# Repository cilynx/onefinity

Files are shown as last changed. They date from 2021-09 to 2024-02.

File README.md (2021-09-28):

# Onefinity
Customizations and Extensions for Onefinity CNC Machines

## Calibration

Easy to work with objects of known dimensions for validating everything is dialed in correctly.

## Pen Plotter

Plot with multiple pens and automatic color changes.

Onefinity CNC: Pen Plotter Multi-Row Magazine (https://youtu.be/0U2Qaqqsit8)

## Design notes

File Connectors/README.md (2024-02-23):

# Stock Onefinity Connectors

| Manufacturer | Amazon | Digikey | Mouser | Description | Use |
| - | - | - | - | - | - |
| [Molex 39-01-3046](https://www.molex.com/pdm_docs/sd/039013046_sd.pdf) | [B07DLLN2VL](https://amzn.to/46uqZdA) (5-circuit set of pins and housings) | [WM17195-ND](https://www.digikey.com/en/products/detail/molex/0039013046/7062835) | [538-39-01-3046](https://www.mouser.com/ProductDetail/Molex/39-01-3046?qs=1XlfjIQj4rzRlofcDRhtUQ%3D%3D) | Mini-Fit Jr. 4 Pin Female Inline Housing (4.20mm pitch). Use with 39-00-0041 Pins. | M0-M3 connection blocks built into the rails. |
| [Molex 39-00-0041](https://www.molex.com/pdm_docs/sd/039000041_sd.pdf) | [B07DLLN2VL](https://amzn.to/46uqZdA) (5-circuit set of pins and housings) | [WM2500-ND](https://www.digikey.com/en/products/detail/molex/0039000041/61445) | [538-39-00-0041](https://www.mouser.com/ProductDetail/Molex/39-00-0041/?qs=jsoPY5EnoNugPq%2FRPe5I8w%3D%3D) | Mini-Fit Jr. Male Crimp Pin. Use with 39-01-3046 Housings. | Pins for the above housing. |
| [Molex 39-01-3045](https://tools.molex.com/pdm_docs/sd/039013045_sd.pdf) | [B07DLLN2VL](https://amzn.to/46uqZdA) (5-circuit set of pins and housings) | [WM13487-ND](https://www.digikey.com/en/products/detail/molex/0039013045/3160117) | [538-39-01-3045](https://www.mouser.com/ProductDetail/Molex/39-01-3045/?qs=1XlfjIQj4rw5awNar2tWGQ%3D%3D) | Mini-fit Jr 4 Pin Male Inline Housing (4.20mm pitch). Use with 39-00-0039 Female Pins | M0-M3 cable ends that plug into the blocks on the rails. |
| [Molex 39-00-0039](https://www.molex.com/pdm_docs/sd/039000039_sd.pdf) | [B07DLLN2VL](https://amzn.to/46uqZdA) (5-circuit set of pins and housings) | [WM2501-ND](https://www.digikey.com/en/products/detail/molex/0039000039/61448) | [538-39-00-0039](https://www.mouser.com/ProductDetail/Molex/39-00-0039/?qs=jsoPY5EnoNukaZLXtX9KoA%3D%3D) | Mini-Fit Jr. Female Crimp Pin. Use with 39-01-3045 Housings | Pins for the above housing. |
| [Molex 11-03-0044](https://tools.molex.com/pdm_docs/ats/ATS-011030044.pdf) | [B08LHDH9KN](https://amzn.to/44uFX1e) | [WM9918-ND](https://www.digikey.com/en/products/detail/molex/0011030044/210947) | [538-11-03-0044](https://www.mouser.com/ProductDetail/Molex/11-03-0044?qs=zb2cXSD1GSER3iz39m7%252B5g%3D%3D) | Extraction Tool for Mini-Fit Jr. Crimp Pins |
| [Amphenol 10127716-04LF](https://www.amphenol-cs.com/minitek-pwr-3-0-1012771604lf.html) | [B078Q798L9](https://amzn.to/3PH550O) (5-circuit set of pins and housings) | [609-4816-ND](https://www.digikey.com/en/products/detail/amphenol-cs-fci/10127716-04LF/4996158) | [649-10127716-04LF](https://www.mouser.com/ProductDetail/Amphenol-FCI/10127716-04LF?qs=Bf%2FVgRlSfyE9WovoNUAZ0w%3D%3D) | Minitek Pwr 3.0 Male Inline Housing (3mm pitch). Use with 10127718-001LF Female Pins. | M0-M3 cable ends that plug into the blocks on the Buildbotics controller. |
| [Amphenol 10127718-001LF](https://www.amphenol-cs.com/minitek-pwr-3-0-10127718001lf.html) | [B078Q798L9](https://amzn.to/3PH550O) (5-circuit set of pins and housings) | [609-4845-1-ND](https://www.digikey.com/en/products/detail/amphenol-cs-fci/10127718-001LF/4996181) | [649-10127718-001LF](https://www.mouser.com/ProductDetail/Amphenol-FCI/10127718-001LF?qs=Bf%2FVgRlSfyE%2FaXnoRiR86A%3D%3D) | Minitek Pwr 3.0 Female Crimp Pin. Use with 10127716-04LF housings. | Pins for the above housing. |
| [Amphenol 10127717-04LF](https://www.amphenol-cs.com/minitek-pwr-3-0-1012771704lf.html) | [B078Q798L9](https://amzn.to/3PH550O) (5-circuit set of pins and housings) | [609-4824-ND](https://www.digikey.com/en/products/detail/amphenol-cs-fci/10127717-04LF/4996170) | [649-10127717-04LF](https://www.mouser.com/ProductDetail/Amphenol-FCI/10127717-04LF?qs=Bf%2FVgRlSfyENFCymmLKBBg%3D%3D) | Minitek Pwr 3.0 Female Inline Housing (3mm pitch). Use with 10127719-001LF Male Pins. | M0-M3 connection blocks built into the Buildbotics controller. |
| [Amphenol 10127719-001LF](https://www.amphenol-cs.com/minitek-pwr-3-0-10127719001lf.html) | [B078Q798L9](https://amzn.to/3PH550O) (5-circuit set of pins and housings) | [609-4846-1-ND](https://www.digikey.com/en/products/detail/amphenol-cs-fci/10127719-001LF/4996185) | [649-10127719-001LF](https://www.mouser.com/ProductDetail/Amphenol-FCI/10127719-001LF?qs=Bf%2FVgRlSfyFCUst32mYSEg%3D%3D) | Minitek Pwr 3.0 Male Crimp Pin. Use with 10127717-04LF housings. | Pins for the above housing. |
| [Amphenol 10129274-030LF](https://www.amphenol-cs.com/minitek-pwr-3-0-cable-assembly-10129274030lf.html) | [B0195V4OVA](https://amzn.to/433VgwZ) | [609-5574-ND](https://www.digikey.com/en/products/detail/amphenol-cs-fci/10129274-030LF/5185630) | [649-10129274-030LF](https://www.mouser.com/ProductDetail/Amphenol-FCI/10129274-030LF?qs=cgQJD%2FpJz0xA4ycwVwK8Zw%3D%3D) | Extraction Tool for Minitek Pwr 3.0 Crimp Pins |

Inspired by [this thread](https://forum.onefinitycnc.com/t/wire-connections/1880) on the Onefinity Forum.  

It's worth noting that Minitek Pwr 3.0 and 4.2 are [interchangeable and inter-pluggable](https://www.automation.com/en-us/products/product08/fci-announces-minitek-pwr-30-42-connectors) with Molex Micro-Fit and Mini-Fit Jr. respectively.  

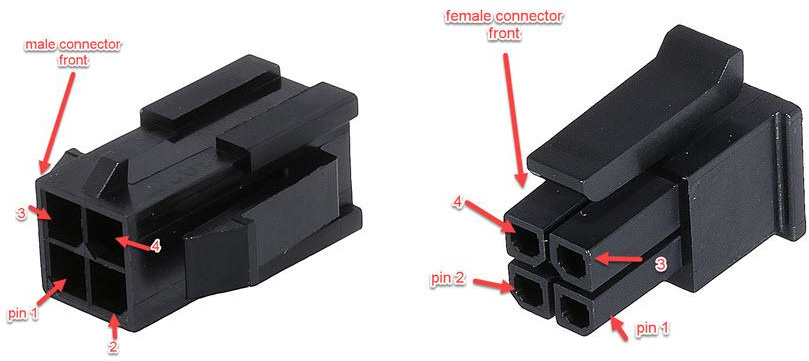
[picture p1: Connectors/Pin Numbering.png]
pins


# BTT Octopus v1.1

| Header | Code | Pins | Default Function | Octofinity Function | Connector | Issues |
| - | - | - | - | - | - | - |
| J3 | MOTOR0 || X-Axis | M0 (X-Axis) | 4-pin JST XH | https://github.com/cilynx/onefinity/issues/3 |
| J4 | MOTOR1 || Y-Axis || 4-pin JST XH |
| J7 | MOTOR2_1 || Z-Axis | M3 (Z-Axis) | 4-pin JST XH | https://github.com/cilynx/onefinity/issues/3 |
| J5 | MOTOR2_2 || Z-Axis 2 (for dual-Z) | | 4-pin JST XH |
| J6 | MOTOR3 || Accessory || 4-pin JST XH |
| J10 | MOTOR4 || Extruder 0 | M4 (Extruder) | 4-pin JST XH | https://github.com/cilynx/onefinity/issues/2, https://github.com/cilynx/onefinity/issues/3 |
| J11 | MOTOR5 || Extruder 1 | M1 (Y-Axis 0) | 4-pin JST XH | https://github.com/cilynx/onefinity/issues/3 |
| J13 | MOTOR6 || Extruder 2 | M2 (Y-Axis 1) | 4-pin JST XH | https://github.com/cilynx/onefinity/issues/3 |
| J12 | MOTOR7 || Extruder 3 || 4-pin JST XH |
| J26 | Raspberry Pi | PD5 (TX2), PD6 (RX2) | Raspberry Pi || 2x5 Dupont |
| J40 | SENSOR | PB7 | Touch Probe | Touch Probe | 3-pin JST XH |
| J43 | BL_TOUCH | PB6, PB7 | [BLTouch Probe](https://amzn.to/44pBa0Y) || 1x5 Dupont |
| J44 | TB | PF3 | Bed Temperature || 2-pin JST XH |
| J45 | T0 | PF4 | Extruder 0 Temperature | Extruder Temperature | 2-pin JST XH | https://github.com/cilynx/onefinity/issues/1 |
| J46 | T1 | PF5 | Extruder 1 Temperature || 2-pin JST XH |
| J48 | T2 | PF6 | Extruder 2 Temperature || 2-pin JST XH |
| J49 | T3 | PF7| Extruder 3 Temperature || 2-pin JST XH |
| J50 | FAN0 | PA8 | Print cooling fan || 2-pin JST XH |
| J51 | FAN1 | PE5 | Heater fan 1 | Extruder Fan | 2-pin JST XH | https://github.com/cilynx/onefinity/issues/1 |
| J52 | FAN2 | PD12 | Heater fan 2 || 2-pin JST XH |
| J53 | FAN3 | PD13 | Heater fan 3 || 2-pin JST XH |
| J54 | FAN4 | PD14 | Heater fan 4 || 2-pin JST XH |
| J55 | FAN5 | PD15 | Heater fan 5 || 2-pin JST XH |
| J57 | FAN6 || Always-on fan 0 || 2-pin JST XH | https://github.com/cilynx/onefinity/issues/4 |
| J56 | FAN7 || Always-on fan 1 || 2-pin JST XH |
| J70 | TFT | PA9 (TX1), PA10 (RX1) | TFT Display || 5-pin JST XH |
| J73 | I2C & EEPROM | PB8 (SCL), PB9 (SDA) | I2C & EEPROM || 2x4 Dupont |

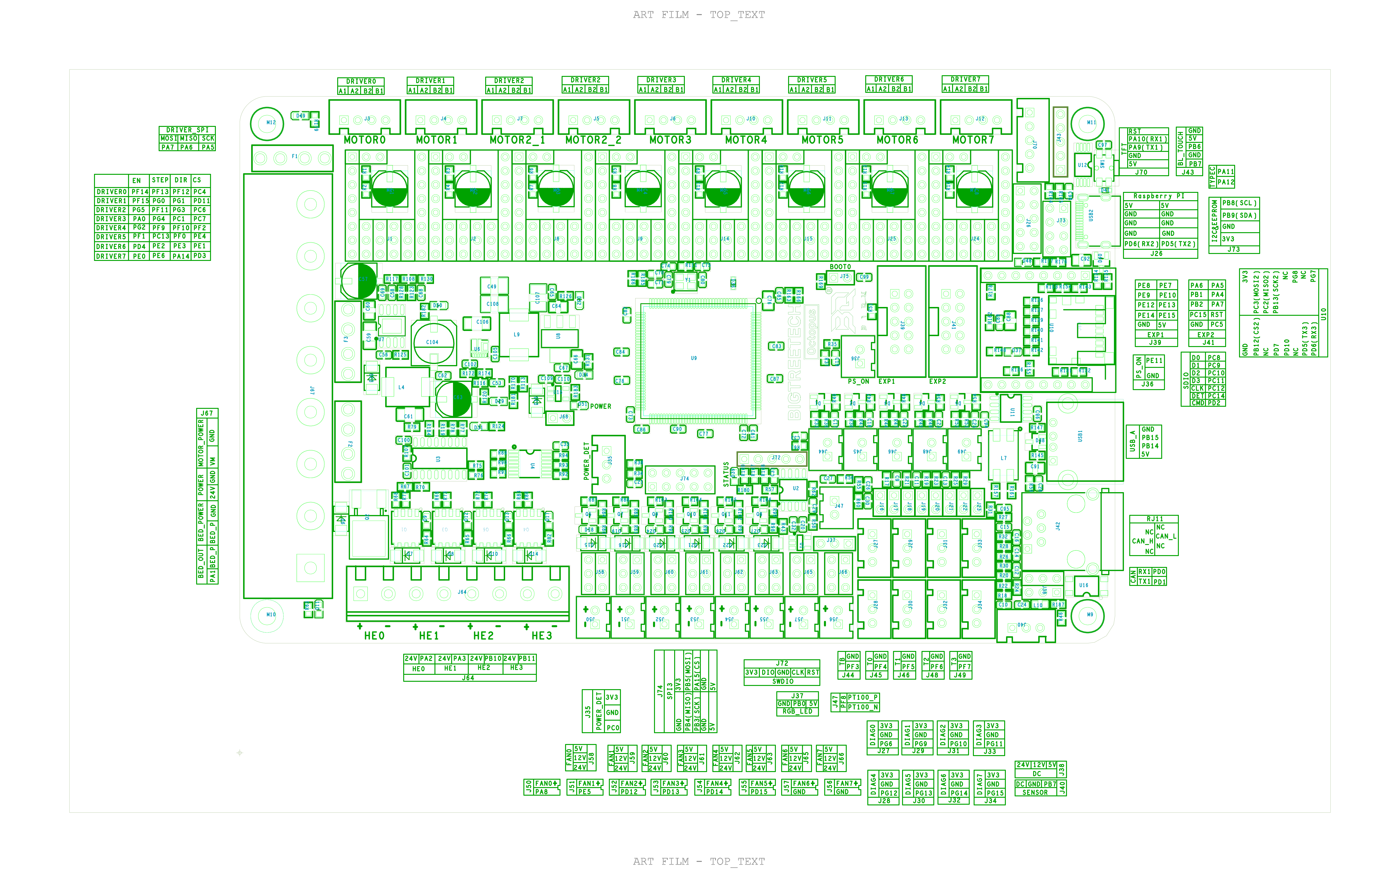
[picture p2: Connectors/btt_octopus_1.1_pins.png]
Octopus v1.1 Pinout


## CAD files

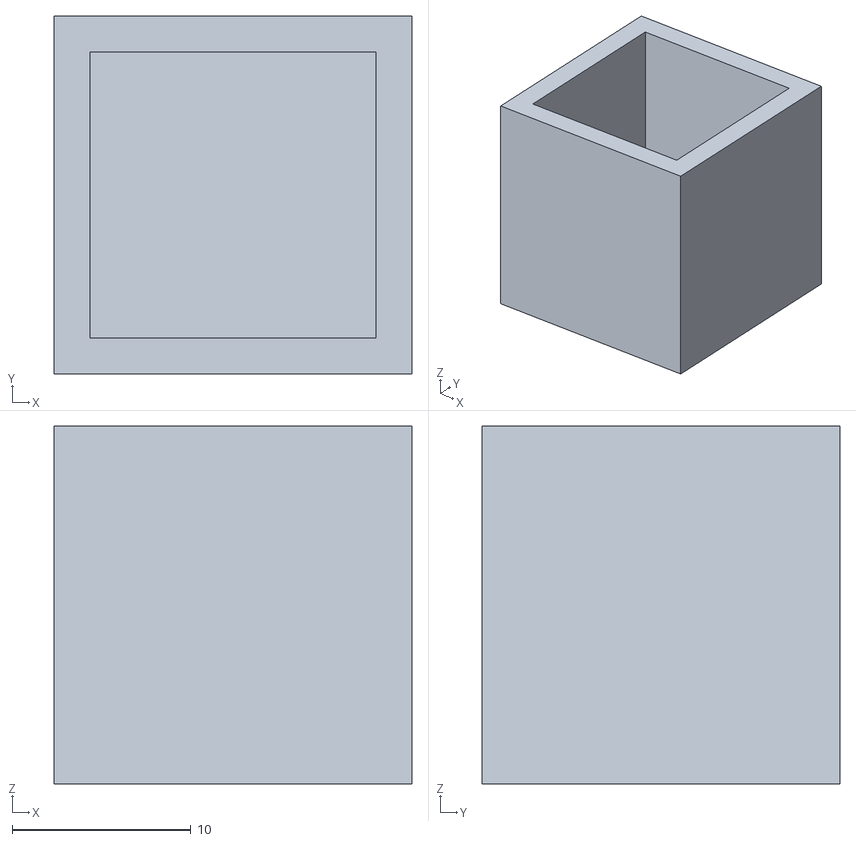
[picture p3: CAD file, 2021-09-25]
Calibration/20mm Cube.stl
20.0 x 20.0 x 20.0

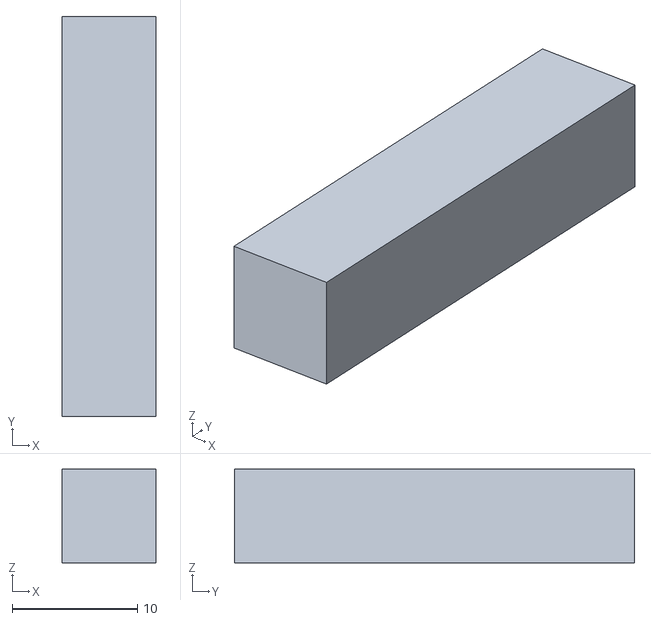
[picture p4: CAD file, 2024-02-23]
Hemera/bed_spacers.stl
7.50 x 32.0 x 7.50

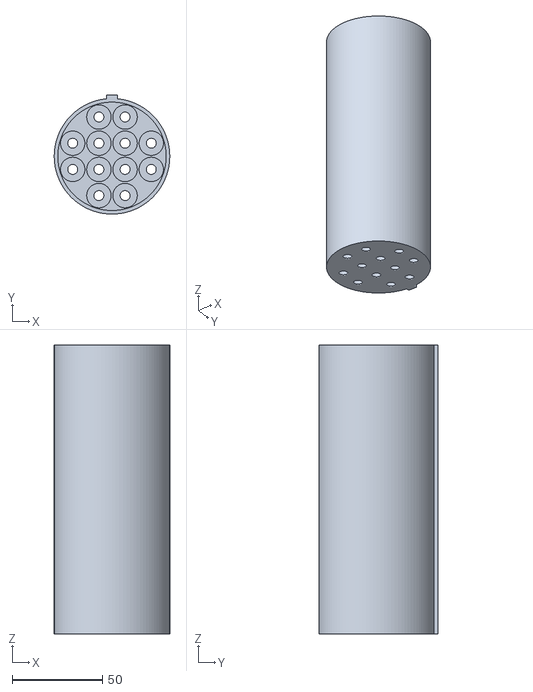
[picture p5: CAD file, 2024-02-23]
Pen Plotter/Spindle Magazine - 12x Fine Point Sharpie.stl
64.0 x 66.0 x 160.0

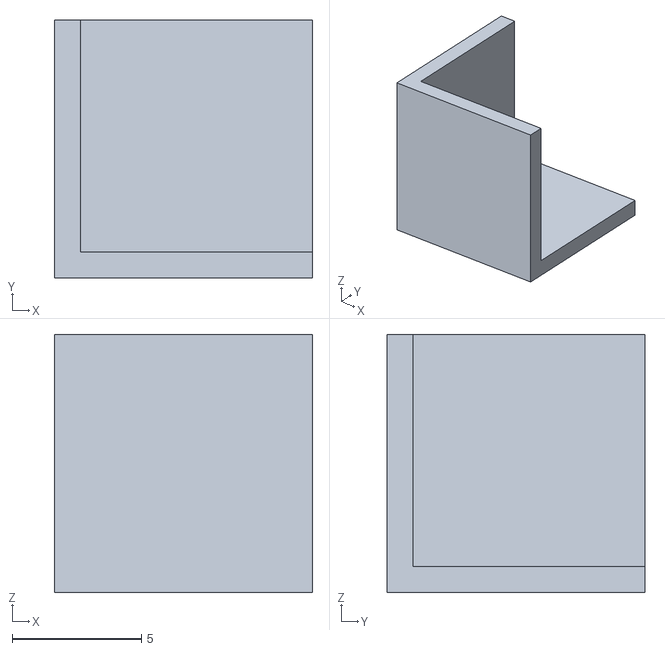
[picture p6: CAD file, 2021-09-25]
Calibration/10mm Cube.stl
10.0 x 10.0 x 10.0

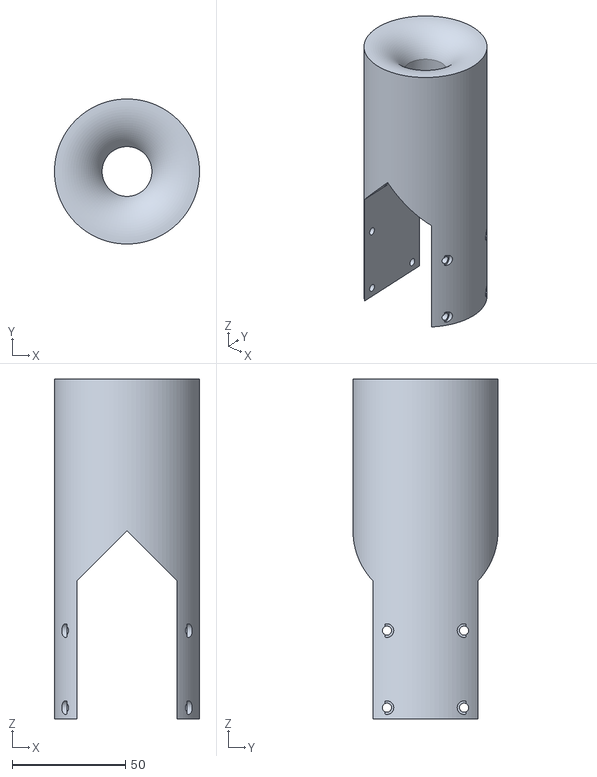
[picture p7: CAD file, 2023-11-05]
Hemera/spindle_mount.stl
64.0 x 64.0 x 150.0

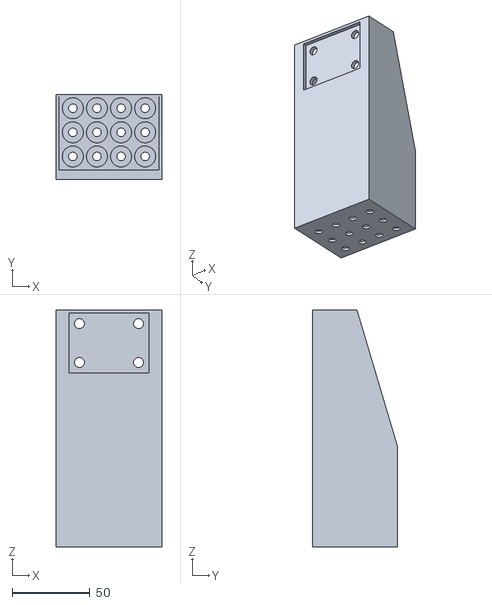
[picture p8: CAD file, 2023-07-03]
Pen Plotter/Pen Magazine.stl
68.0 x 54.5 x 152.4

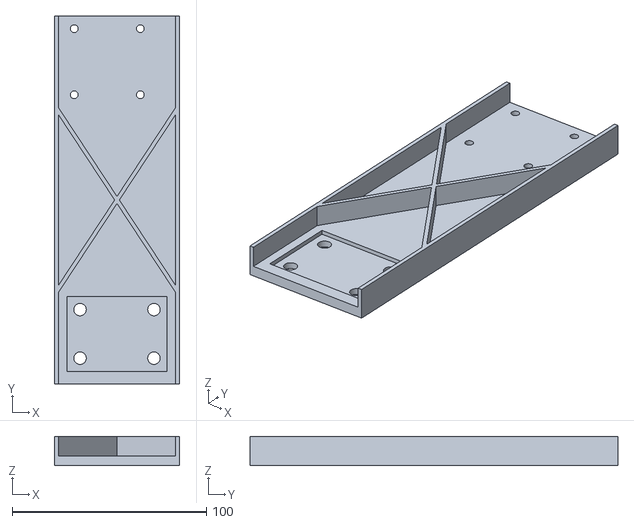
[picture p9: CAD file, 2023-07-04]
Hemera/mounting_plate.stl
64.3 x 189.1 x 15.0

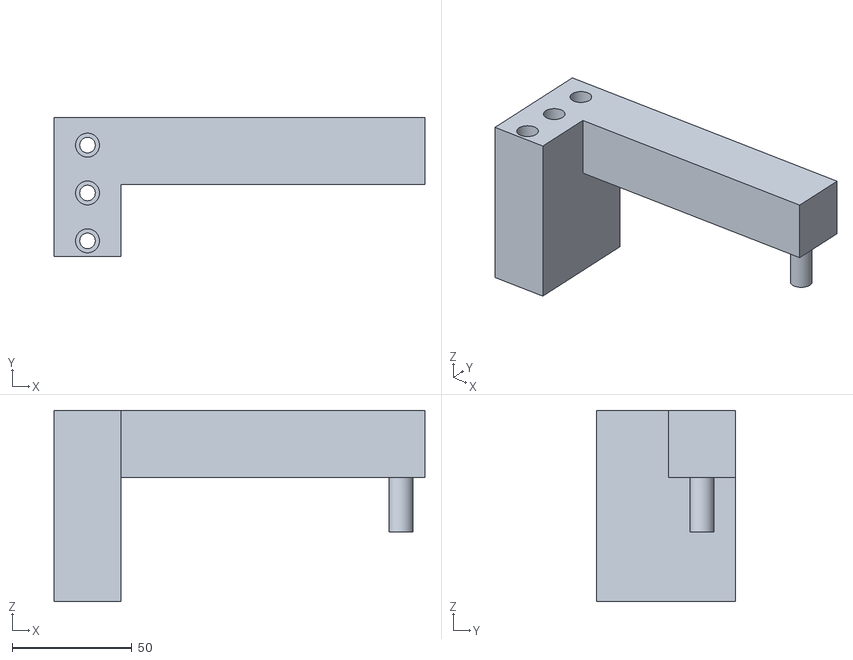
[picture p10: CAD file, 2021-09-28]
Pen Plotter/Pen Changer XY.stl
155.0 x 58.0 x 80.0

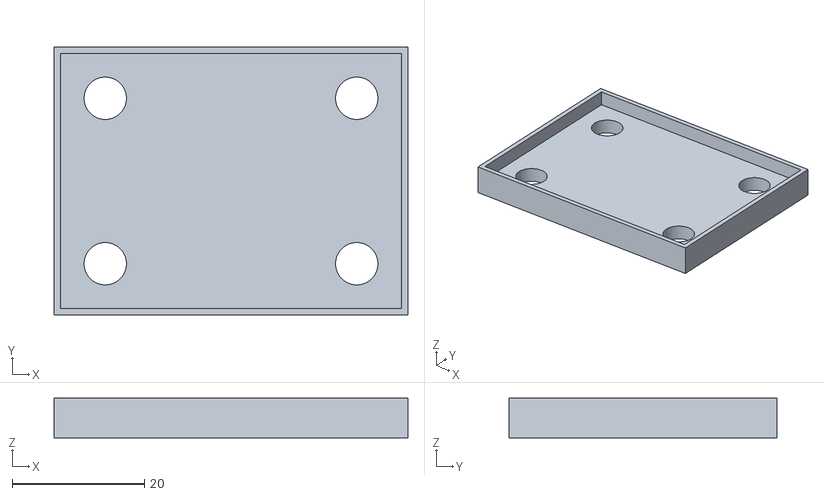
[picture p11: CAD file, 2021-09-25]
Pen Plotter/Mounting Bracket Test.stl
53.5 x 40.5 x 6.00

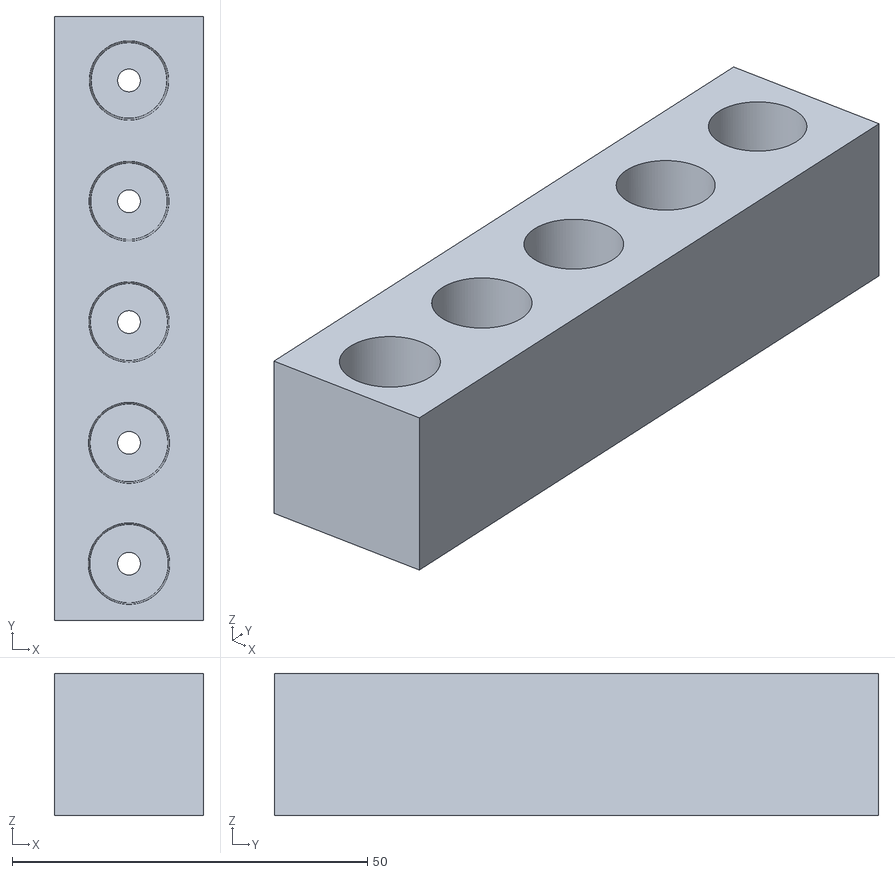
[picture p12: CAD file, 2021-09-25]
Pen Plotter/Pen Barrel Test.stl
21.0 x 85.0 x 20.0

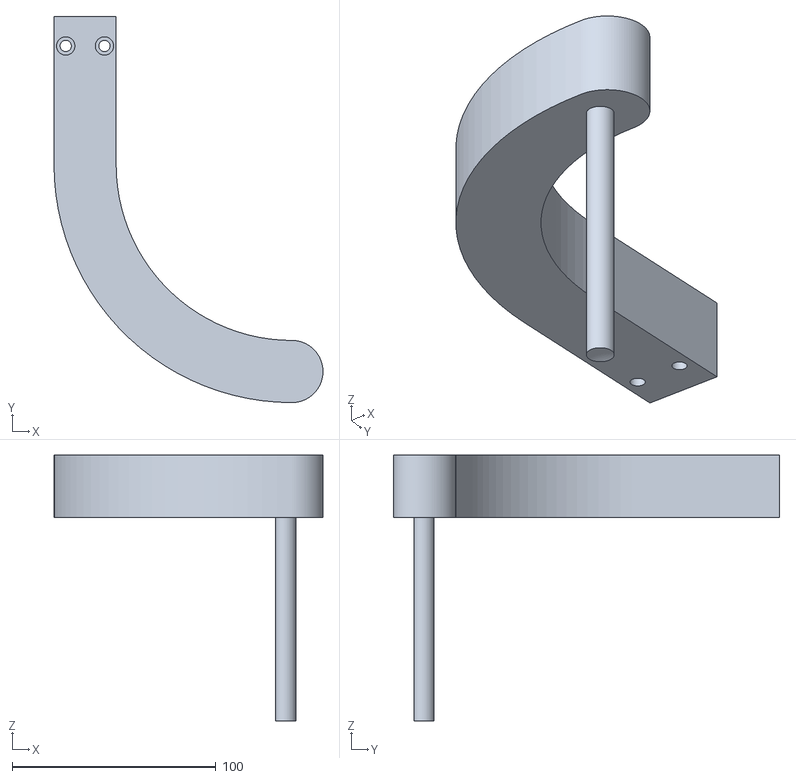
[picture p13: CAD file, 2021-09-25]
Pen Plotter/Pen Changer X.stl
132.0 x 189.5 x 130.4

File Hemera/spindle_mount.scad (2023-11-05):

// Hemera
hemera_depth = 44;
hemera_height = 44;

// Bolt Holes
hb_w = 34;
hb_h = 34;

// Body Parameters
spindle_d = 64;
channel_d = 20;
height = 150;

$fn=100;

module bolt_hole() {
    thread_d = 4;   // M3 bolts
    head_d = 6;   // Allen head
    depth = 4.5;  // How much meat to leave
    hole_h = 20;     // Keep plenty of clearance

    cylinder(h=hole_h, d=thread_d);
    translate([0, 0, depth])
    cylinder(h=hole_h, d=head_d);
}

difference() {
    
    // Main Body
    cylinder(h=height, d=spindle_d);
    
    // Wiring Channel
    cylinder(h=height, d=channel_d);
    
    // Rounded Top Chamfer
    translate([0,0,height-channel_d])
    rotate_extrude() {
        translate([channel_d/2-0.001,0,0])
        difference() {
            square(20);
            translate([20,0,0])
            circle(20);
        }
    }

    // Slot for Hemera
    translate([-hemera_depth/2, -spindle_d/2])
    cube([hemera_depth, spindle_d, hemera_height+hb_h/2]);

    // Bottom Chamfer to Make it Printable
    translate([0, -spindle_d/2, hemera_height-hemera_depth/2+hb_h/2])
    rotate([0, -45, 0])
    cube([hemera_depth/sqrt(2), spindle_d, hemera_depth/sqrt(2)]);
 
    translate([0, 0, hemera_height+hb_h/2])
    cylinder(h=150, d1=hemera_depth, d2=0);
    
    // Bolt Holes
    hb_m = hemera_height/2;
    hd2 = hemera_depth/2;
    
    translate([hd2, hb_w/2, hb_m-hb_h/2]) rotate([0, 90, 0]) bolt_hole();
    translate([hd2, -hb_w/2, hb_m-hb_h/2]) rotate([0, 90, 0]) bolt_hole();
    translate([hd2, hb_w/2, hb_m+hb_h/2]) rotate([0, 90, 0]) bolt_hole();
    translate([hd2, -hb_w/2, hb_m+hb_h/2]) rotate([0, 90, 0]) bolt_hole();

    translate([-hd2, hb_w/2, hb_m-hb_h/2]) rotate([0, -90, 0]) bolt_hole();
    translate([-hd2, -hb_w/2, hb_m-hb_h/2]) rotate([0, -90, 0]) bolt_hole();
    translate([-hd2, hb_w/2, hb_m+hb_h/2]) rotate([0, -90, 0]) bolt_hole();
    translate([-hd2, -hb_w/2, hb_m+hb_h/2]) rotate([0, -90, 0]) bolt_hole();


}

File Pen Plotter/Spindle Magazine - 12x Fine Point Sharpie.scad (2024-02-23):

/////////////////////////////////////////////////////////////
// Fine Point Sharpies 12-Pack
// https://amzn.to/3BqGQeS
/////////////////////////////////////////////////////////////

nib_d = 5.5;            // 4.6 at the collar
slot_d = 13.5;          // 12.5 at 65
slot_h = 80;
height = 160;
spindle_d = 64;
space = 1;
wall = 2;
key = 6;

shift = slot_d + space;

$fn=100;

pop = [[0,1,1,0],
       [1,1,1,1],
       [1,1,1,1],
       [0,1,1,0]];

difference() {
    cylinder(d=spindle_d, h=height);
    translate([0, 0, slot_h])
    cylinder(d=spindle_d-2*wall, h=height);
    translate([-3/2*shift, -3/2*shift, 0])
    for(i=[0:3]) {
        for(j=[0:3]) {
            if(pop[i][j]) {
                translate([shift*i, shift*j, 0.5])
                cylinder(d=slot_d, h=slot_h);
                translate([shift*i, shift*j, -1])
                cylinder(d=nib_d, h=2);
            }
        }
    }
}

translate([-key/2, spindle_d/2-wall])
cube([key, 2/3*key, height]);

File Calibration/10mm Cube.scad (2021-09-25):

difference() {
  cube(10);
  translate([1,1,1])
  cube(10);
}

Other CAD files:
Calibration/20mm Cube.scad
Hemera/bed_spacers.scad
Hemera/mounting_plate.scad
Pen Magazine.scad
Pen Plotter/Mounting Bracket Test.scad
Pen Plotter/Pen Barrel Test.scad
Pen Plotter/Pen Changer X.scad
Pen Plotter/Pen Changer XY.scad
Pen Plotter/Pen Magazine.scad
Pen Plotter/Pen Nib Test.scad

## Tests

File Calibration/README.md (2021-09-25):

# Calibration

When I printed my first pen magazine on the Kossel after having done earlier revisions on the EPAX, it came out around 10% smaller than I expected, so I made up a couple of calibration objects here to print on both printers to figure out what's going on.

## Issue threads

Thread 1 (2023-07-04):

Hemera fan and thermistor connections are loose

cilynx, 2023-07-04:
Both the fan and thermistor have 2-pin female Dupont ends.  Connections on the board are JST XH.

cilynx, 2023-07-04:
Currently using [2-pin JST XH extensions](https://amzn.to/3CXi4E3), but while the male XH technically fits the female Dupont, the pins are too short and the connection isn't solid.  I haven't been able to find 2-pin Duport to JST XH extensions, so I'll likely cut the Dupont ends off of the thermistor and fan and crimp on JST XH connectors to use my existing JST XH extensions.

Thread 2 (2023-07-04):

Extruder stepper wiring pulls out on extreme moves

cilynx, 2023-07-04:
Right now it's a janky chain of short Dupont cables.  Ordered some [2-meter JST XH cables](https://amzn.to/445VTr0) which should be delivered this week.

cilynx, 2023-07-04:
Similar to #3, I should probably consider doing a Micro-Fit end on the extruder stepper for consistency with the other axes and do a Micro-Fit to to JST XH jumper inside the controller housing.

cilynx, 2023-07-07:
Replaced the horrible Dupont chain with one of the 2-meter JST cables today and while it technically works, 2-meters isn't long enough as I now have to keep the controller very close to the Y-rail and in the middle of the machine so it can reach both extremes.  I haven't been able to find anything longer pre-made, so it looks like I'm going to have to make my own cables.

cilynx, 2023-11-05:
Made my own cables and no longer having any wiring faults.  Next up -- drag chains -- #8

cilynx, 2023-11-05:
Made my own cables and no longer having any wiring faults.  Next up -- drag chains -- #8

Closed 2023-11-05.

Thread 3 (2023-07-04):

M0-M3 connections all have dupont pins shoved into the Molex cable ends

cilynx, 2023-07-04:
While just cobbling this together has been surprisingly stable and effective, I want to do something better.  When I make a housing for the board, I should probably make some jumpers with a 4-pin JST XH for the Octopus on one end and a [Molex Micro-Fit housing](https://amzn.to/3NDPBIj) on the other end so the new controller enclosure is plug-and-play with the stock axes cabling.

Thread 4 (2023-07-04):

Stepper driver current and heat

cilynx, 2023-07-04:
I'm running [TMC2209](https://amzn.to/43duKRV)s and they're overheating if I use the 1.8A holding current that the Onefinity motors can take.  Right now, I have them [dialed back to 0.8.](https://github.com/cilynx/onefinity/blob/a1bd0e9fa75cac3d050168686df1042f605f7075/Klipper/printer.cfg#L41) to keep the temperature down.  With some active cooling, I could probably pull this back up to get more torque.

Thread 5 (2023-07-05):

Bed is not perfectly level -- seeing artifacts of nozzle too high and too low in the same first layer

cilynx, 2023-07-05:
Unsurprisingly, the combination of giant piece of glass not designed for this use and heavy duty catering table don't add up to a perfectly flat and level surface.  I think the best bet will be setting up stall homing on Z and doing a bed mesh from there.

cilynx, 2023-07-05:
Seems like folks smarter than me think using sensorless for probing is a bad idea: https://github.com/Klipper3d/klipper/issues/697 -- gonna try a piezo sensor instead.

cilynx, 2023-07-05:
https://www.klipper3d.org/Probe_Calibrate.html

cilynx, 2023-07-05:
https://www.klipper3d.org/Bed_Mesh.html

Closed 2023-07-07.

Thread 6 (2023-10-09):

Controller details

matbee-eth, 2023-10-09:
Are you using the stock buildbotics based controller?

cilynx, 2023-10-09:
For the plotter stuff, I was using the stock buildbotics controller.

For 3d printing, I looked into the possibility of using a standalone heater controller and driving both Y-steppers with a single driver to free up Y' for the extruder motor, but it turned out to be both easier and more cost effective to just switch to a different controller altogether.  I'm now using a BTT Octopus running Klipper which easily drives more axes than I need as well as multiple heaters and fans and such without much fuss.

https://www.youtube.com/watch?v=CBVempioNRo

The biggest issue right now is heating the giant glass bed.  I'm currently using an 800W heating coil and it's not nearly enough.  Next steps are going to be improved insulation below the coil and potentially a second 800W coil.

matbee-eth, 2023-10-10:
Do you have the pin layout diagram anywhere, or is it self explanatory on the controller board? I'm excited to give this a go. At first I'll just use the print volume of my heated Ender board until I can figure out a larger heated bed volume.

cilynx, 2023-10-10:
Pin layout and info to make cables.  I highly recommend making a set of nice cables with the proper end connectors.  Troubleshooting "is something really broken or are my makeshift cables loose again?" isn't much fun.
https://github.com/cilynx/onefinity/tree/main/Connectors

A (crappy, not very rigid -- I really need to redesign this thing) Hemera mount that attaches to the front of the spindle mount.
https://github.com/cilynx/onefinity/tree/main/Hemera

Klipper config:
https://github.com/cilynx/onefinity/tree/main/Klipper

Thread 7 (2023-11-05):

Heating the Giant Glass Bed

cilynx, 2023-11-05:
I'm currently using 100ft of 120V pipe wrap.  It pulls ~1100W at room temperature and is down to ~375W in the ballpark of 40C and that's all the higher it goes in the current arrangement.  Next step is to come up with a mechanism to arrange and hold the coil for maximum uniform coverage.  This will both reduce hot/cold spots on the bed and may get me a bit more power as well as the coil appears to have a positive temperature coefficient so reducing its hot spots might keep the overall power higher.

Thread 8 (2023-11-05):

Drag chains

cilynx, 2023-11-05:
Now that I've made up my own cabling, things are mostly working well, but I really need to do some drag chains to clean things up and reduce the chances of loose cabling getting hung up.

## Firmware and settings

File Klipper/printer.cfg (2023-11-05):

# This file contains common pin mappings for the BigTreeTech Octopus
# and Octopus Pro boards. To use this config, start by identifying the
# micro-controller on the board - it may be an STM32F446, STM32F429,
# or an STM32H723.  Select the appropriate micro-controller in "make
# menuconfig" and select "Enable low-level configuration options". For
# STM32F446 boards the firmware should be compiled with a "32KiB
# bootloader" and a "12MHz crystal" clock reference. For STM32F429
# boards use a "32KiB bootloader" and an "8MHz crystal". For STM32H723
# boards use a "128KiB bootloader" and a "25Mhz crystal".

# See docs/Config_Reference.md for a description of parameters.

# Mainsail Configuration
# https://docs.mainsail.xyz/setup/configuration
[include mainsail.cfg]

# Home Z to clear the table, then X to get off to one side, then Y
[homing_override]
gcode:
 G28 Z
 G28 X
 G28 Y
 G0 X815 Y815

# Driver0
[stepper_x]
step_pin: PF13
dir_pin: PF12
enable_pin: !PF14
microsteps: 16
rotation_distance: 10
# endstop_pin: PG6
endstop_pin: tmc2209_stepper_x:virtual_endstop
homing_retract_dist: 0
position_endstop: 816
position_max: 816
homing_speed: 20

[tmc2209 stepper_x]
uart_pin: PC4
diag_pin: PG6
run_current: 0.8
#stealthchop_threshold: 999999
driver_SGTHRS: 80  # 255 is most sensitive value, 0 is least sensitive

# Driver1
#[stepper_y]
#step_pin: PG0
#dir_pin: PG1
#enable_pin: !PF15
#microsteps: 16
#rotation_distance: 10
#endstop_pin: PG9
#endstop_pin: tmc2209_stepper_y:virtual_endstop
#homing_retract_dist: 0
#position_endstop: 0
#position_max: 816
#homing_speed: 10

# Driver2
[stepper_z]
step_pin: PF11
dir_pin: !PG3
enable_pin: !PG5
microsteps: 16
rotation_distance: 4
#endstop_pin: PG10
endstop_pin: tmc2209_stepper_z:virtual_endstop
homing_retract_dist: 0
position_endstop: 76.2 # Lowest carriage position
position_max: 76.2
homing_speed: 15

[tmc2209 stepper_z]
uart_pin: PC6
diag_pin: PG10
run_current: 0.8
#stealthchop_threshold: 999999
driver_SGTHRS: 80  # 255 is most sensitive value, 0 is least sensitive

# Driver3
# The Octopus only has 4 heater outputs which leaves an extra stepper
# This can be used for a second Z stepper, dual_carriage, extruder co-stepper,
# or other accesory such as an MMU
#[stepper_]
#step_pin: PG4
#dir_pin: PC1
#enable_pin: PA0
#endstop_pin: PG11
#...

# Driver4
[extruder]
step_pin: PF9
dir_pin: PF10
enable_pin: !PG2
microsteps: 16
rotation_distance: 8
nozzle_diameter: 0.400
filament_diameter: 1.750
heater_pin: PA2 # HE0
sensor_pin:  PF4 # T0
min_extrude_temp: -100
sensor_type: EPCOS 100K B57560G104F
control: pid
pid_Kp: 22.2
pid_Ki: 1.08
pid_Kd: 114
min_temp: -100
max_temp: 250

[tmc2209 extruder]
uart_pin: PF2
run_current: 0.800
#stealthchop_threshold: 999999

#[filament_switch_sensor material_0]
#switch_pin: PG12

# Driver5
#[extruder1]
#step_pin: PC13
#dir_pin: PF0
#enable_pin: !PF1
#heater_pin: PA3 # HE1
#sensor_pin: PF5 # T1
#...

# Driver5
[stepper_y]
step_pin: PC13
dir_pin: !PF0
enable_pin: !PF1
microsteps: 16
rotation_distance: 10
#endstop_pin: PG13
endstop_pin: tmc2209_stepper_y:virtual_endstop
homing_retract_dist: 0
position_endstop: 816
position_max: 816
homing_speed: 20

[tmc2209 stepper_y]
uart_pin: PE4
diag_pin: PG13
run_current: 0.800
#stealthchop_threshold: 999999
driver_SGTHRS: 80  # 255 is most sensitive value, 0 is least sensitive


#[filament_switch_sensor material_1]
#switch_pin: PG13

# Driver6
#[extruder2]
#step_pin: PE2
#dir_pin: PE3
#enable_pin: !PD4
#heater_pin: PB10 # HE2
#sensor_pin: PF6 # T2
#...

# Driver6
[stepper_y1]
step_pin: PE2
dir_pin: !PE3
enable_pin: !PD4
microsteps: 16
rotation_distance: 10
#endstop_pin: PG14
endstop_pin: tmc2209_stepper_y:virtual_endstop

[tmc2209 stepper_y1]
uart_pin: PE1
diag_pin: PG14
run_current: 0.800
#stealthchop_threshold: 999999
driver_SGTHRS: 80  # 255 is most sensitive value, 0 is least sensitive

#[filament_switch_sensor material_2]
#switch_pin: PG14

# Driver7
#[extruder3]
#step_pin: PE6
#dir_pin: PA14
#enable_pin: !PE0
#heater_pin: PB11 # HE3
#sensor_pin: PF7 # T3
#...

#[filament_switch_sensor material_3]
#switch_pin: PG15

[heater_bed]
heater_pin: PA1
sensor_pin: PF3 # TB
sensor_type: ATC Semitec 104GT-2
control: watermark
min_temp: -100
max_temp: 130

[fan]
pin: PA8

[heater_fan hemera]
pin: PE5
heater: extruder
heater_temp: 50.0
fan_speed: 1.0

#[heater_fan fan2]
#pin: PD12

#[heater_fan fan3]
#pin: PD13

#[heater_fan fan4]
#pin: PD14

#[controller_fan fan5]
#pin: PD15

[mcu]
serial: /dev/serial/by-id/usb-Klipper_stm32f446xx_350038000951313133353932-if00
# CAN bus is also available on this board

[printer]
kinematics: cartesian
max_velocity: 500
max_accel: 300
max_z_velocity: 20
max_z_accel: 100

########################################
# TMC2209 configuration
########################################

#[tmc2209 stepper_]
#uart_pin: PC7
##diag_pin: PG11
#run_current: 0.650
#stealthchop_threshold: 999999

#[tmc2209 extruder3]
#uart_pin: PD3
#run_current: 0.800
#stealthchop_threshold: 999999

########################################
# TMC2130 configuration
########################################

#[tmc2130 stepper_x]
#cs_pin: PC4
#spi_bus: spi1
##diag1_pin: PG6
#run_current: 0.800
#stealthchop_threshold: 999999

#[tmc2130 stepper_y]
#cs_pin: PD11
#spi_bus: spi1
##diag1_pin: PG9
#run_current: 0.800
#stealthchop_threshold: 999999

#[tmc2130 stepper_z]
#cs_pin: PC6
#spi_bus: spi1
##diag1_pin: PG10
#run_current: 0.650
#stealthchop_threshold: 999999

#[tmc2130 stepper_]
#cs_pin: PC7
#spi_bus: spi1
##diag1_pin: PG11
#run_current: 0.800
#stealthchop_threshold: 999999

#[tmc2130 extruder]
#cs_pin: PF2
#spi_bus: spi1
#run_current: 0.800
#stealthchop_threshold: 999999

#[tmc2130 extruder1]
#cs_pin: PE4
#spi_bus: spi1
#run_current: 0.800
#stealthchop_threshold: 999999

#[tmc2130 extruder2]
#cs_pin: PE1
#spi_bus: spi1
#run_current: 0.800
#stealthchop_threshold: 999999

#[tmc2130 extruder3]
#cs_pin: PD3
#spi_bus: spi1
#run_current: 0.800
#stealthchop_threshold: 999999

[board_pins]
aliases:
    # EXP1 header
    EXP1_1=PE8, EXP1_2=PE7,
    EXP1_3=PE9, EXP1_4=PE10,
    EXP1_5=PE12, EXP1_6=PE13,    # Slot in the socket on this side
    EXP1_7=PE14, EXP1_8=PE15,
    EXP1_9=<GND>, EXP1_10=<5V>,

    # EXP2 header
    EXP2_1=PA6, EXP2_2=PA5,
    EXP2_3=PB1, EXP2_4=PA4,
    EXP2_5=PB2, EXP2_6=PA7,      # Slot in the socket on this side
    EXP2_7=PC15, EXP2_8=<RST>,
    EXP2_9=<GND>, EXP2_10=PC5

# See the sample-lcd.cfg file for definitions of common LCD displays.

# A [probe] section can be defined instead with a pin: setting identical
# to the sensor_pin: for a bltouch
#[bltouch]
#sensor_pin: PB7
#control_pin: PB6
#z_offset: 0
[probe]
pin: ~PB7
z_offset: -0.15

[bed_mesh]
horizontal_move_z: 5
mesh_min: 0, 86
mesh_max: 816, 816
probe_count: 5

#[neopixel my_neopixel]
#pin: PB0

#*# <---------------------- SAVE_CONFIG ---------------------->
#*# DO NOT EDIT THIS BLOCK OR BELOW. The contents are auto-generated.
#*#
#*# [bed_mesh default]
#*# version = 1
#*# points =
#*# 	  0.733750, 1.262500, 1.308750, 0.993750, 0.370000
#*# 	  0.785000, 0.970000, 0.970000, 0.833750, 0.560000
#*# 	  0.547500, 0.648750, 0.610000, 0.522500, 0.352500
#*# 	  0.445000, 0.416250, 0.478750, 0.506250, 0.367500
#*# 	  0.468750, 0.371250, 0.450000, 0.636250, 0.483750
#*# x_count = 5
#*# y_count = 5
#*# mesh_x_pps = 2
#*# mesh_y_pps = 2
#*# algo = lagrange
#*# tension = 0.2
#*# min_x = 0.0
#*# max_x = 816.0
#*# min_y = 86.0
#*# max_y = 816.0

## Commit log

2021-09-22 Add pen magazine
    [Pen Magazine.scad]
2021-09-22 Stabilize, shrink pen holes, adjust mounting bolts https://youtu.be/f_UOvbxFpi8
    [Pen Magazine.scad]
2021-09-23 Pen Magazine Rev 2
    [Pen Magazine.scad, Pen Magazine.stl]
2021-09-23 Add Pen Changer
    [Pen Changer.scad, Pen Changer.stl]
2021-09-27 Move Pen Changer to Y-Rail
    [Pen Changer X.scad, Pen Changer X.stl, Pen Changer XY.scad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]
2021-09-28 Pen Changer Tweaks
    [Pen Changer XY.scad, Pen Changer XY.stl]
2021-09-28 Slide Pen Changer forward to fix Y-homing
    [Pen Changer XY.scad, Pen Changer XY.stl]
2023-06-08 Initial Hemera mounting plate
    [mounting_plate.scad, mounting_plate.stl]
2023-06-08 Tune to fit
    [mounting_plate.scad, mounting_plate.stl]
2023-06-30 Initial Octopus v1.1 config
    [printer.cfg]
2023-07-03 Stock connector info
2023-07-03 Fine Point Sharpie 12-Pack
    [Pen Magazine.scad, Pen Magazine.stl]
2023-07-03 Octopus fan and motor headers
2023-07-03 Calibrate extruder rotation_distance
    [printer.cfg]
2023-07-04 Dial in z_velocity and holding current
    [printer.cfg]
2023-07-04 Reinforced mount
    [mounting_plate.scad, mounting_plate.stl]
2023-07-04 Dial in z position_endstop
    [printer.cfg]
2023-07-05 Configure probe for #5
    [printer.cfg]
2023-07-07 Dialing in the first layer -- fixes #5
    [printer.cfg]
2023-11-05 Spindle mount
    [printer.cfg, spindle_mount.scad, spindle_mount.stl]
2024-02-23 Add J40 Tocuh Probe
2024-02-23 Spindle Mag
    [Spindle Magazine - 12x Fine Point Sharpie.scad, Spindle Magazine - 12x Fine Point Sharpie.stl]
2024-02-23 Shorten and add indexing key
    [Spindle Magazine - 12x Fine Point Sharpie.scad, Spindle Magazine - 12x Fine Point Sharpie.stl]
2024-02-23 Bed spacers
    [bed_spacers.scad, bed_spacers.stl]
